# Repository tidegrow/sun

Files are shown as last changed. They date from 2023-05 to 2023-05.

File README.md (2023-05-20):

# Tidegrow Sun

Tidegrow Sun is an experimental low-power grow light.

## Pinout

Sun uses a non-standard MicroUSB pinout that is compatible with [Tidegrow Curator](https://github.com/tidegrow/curator):

| Signal | Description |
| --- | --- |
| VBUS | Power (5V) |
| D+ | LED PWM control input (3.3V) |
| D- | Photoresistor output (0-3.3V) |
| GND | Ground |

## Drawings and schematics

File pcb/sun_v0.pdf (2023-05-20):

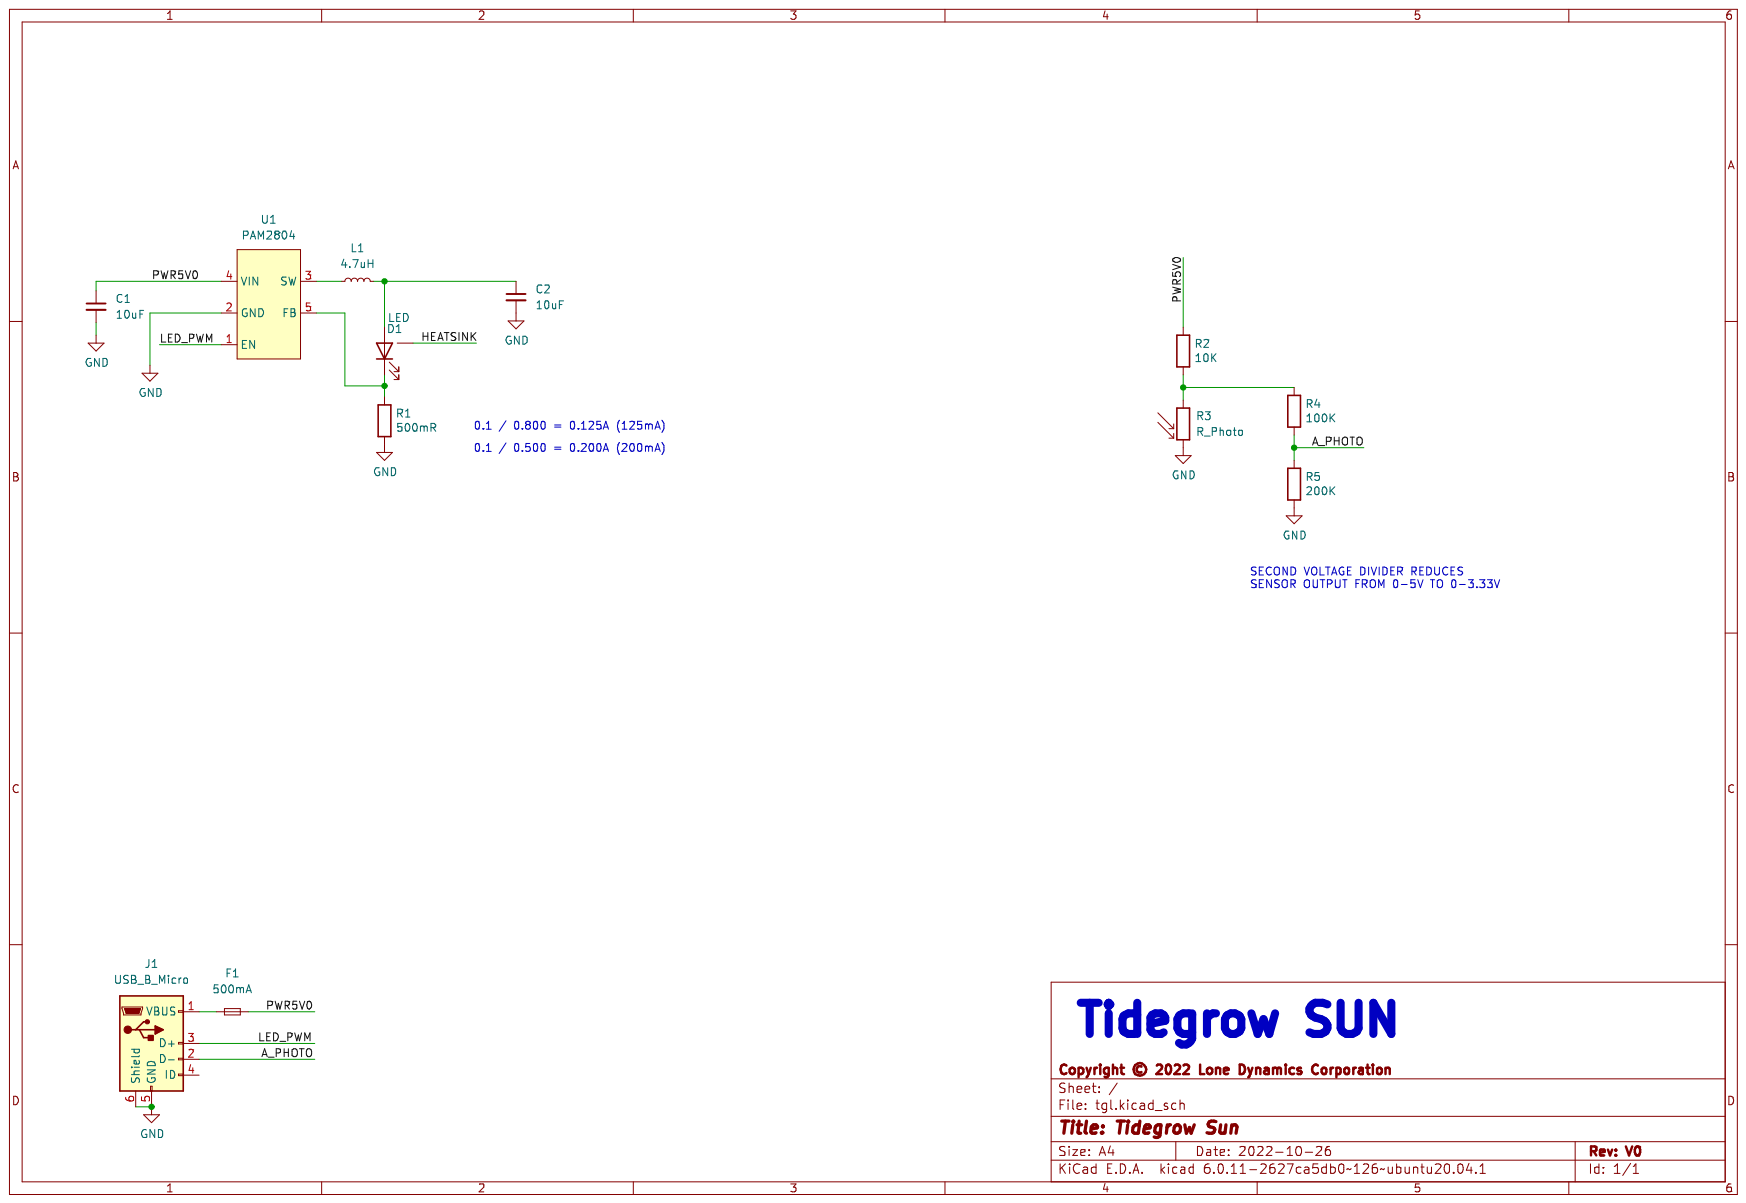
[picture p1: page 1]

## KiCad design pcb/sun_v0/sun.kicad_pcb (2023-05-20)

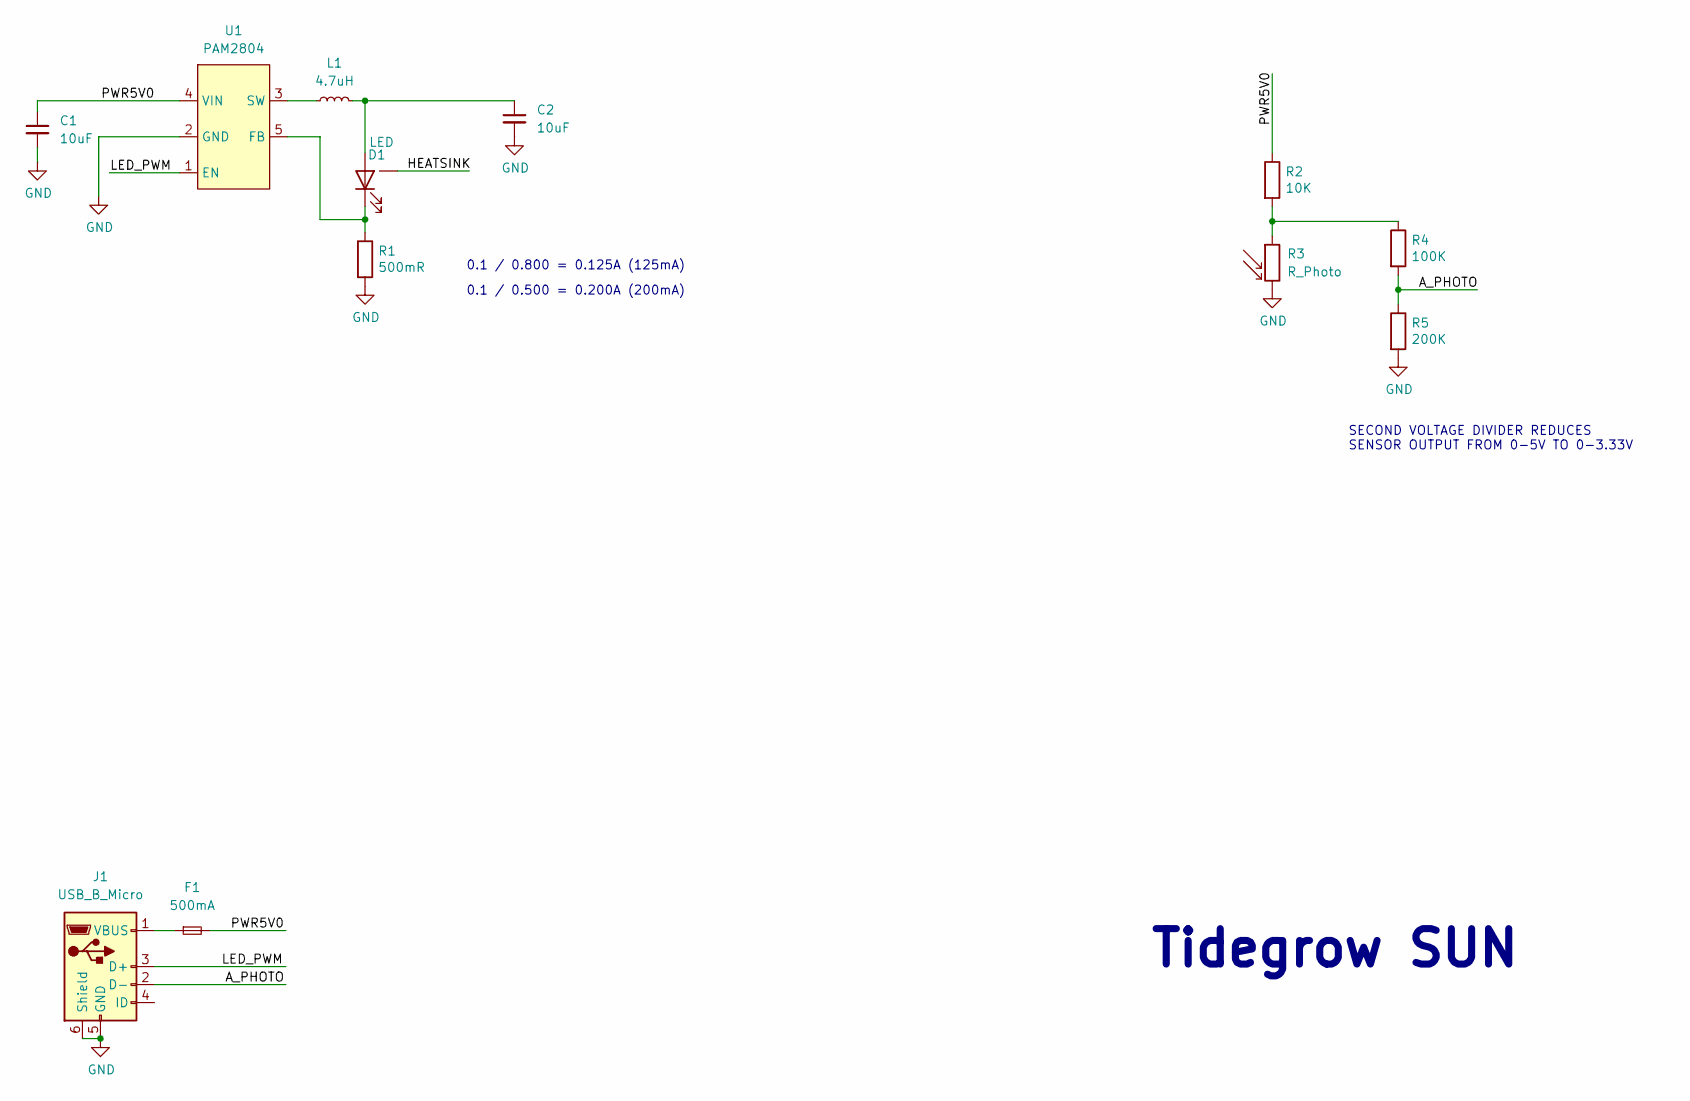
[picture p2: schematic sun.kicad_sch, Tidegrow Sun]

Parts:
C1, C2: 10uF; C_0603_1608Metric
D1: LED; LED_1W_3W_R8
F1: 500mA; Fuse_0805_2012Metric
J1: USB_B_Micro; Generic_Chinese_USB_MicroB_Horizontal_Socket_Circular_Holes
L1: 4.7uH; L_1008_2520Metric
R1: 500mR; R_2010_5025Metric
R2: 10K; R_0603_1608Metric
R3: R_Photo; R_PHOTO_3624
R4: 100K; R_0603_1608Metric
R5: 200K; R_0603_1608Metric
U1: PAM2804; SOT-23-5

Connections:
/A_PHOTO: J1.2 (D-), R4.2, R5.1
/HEATSINK: D1.3 (HEATSINK)
/LED_PWM: J1.3 (D+), U1.1 (EN)
/PWR5V0: C1.1, F1.2, R2.1, U1.4 (VIN)
GND: C1.2, C2.2, J1.5 (GND), J1.6 (Shield), R1.2, R3.2, R5.2, U1.2 (GND)
unnamed: C2.1, D1.2 (A), L1.2
unnamed: D1.1 (K), R1.1, U1.5 (FB)
unnamed: F1.1, J1.1 (VBUS)
unnamed: L1.1, U1.3 (SW)
unnamed: R2.2, R3.1, R4.1

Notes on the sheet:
SECOND VOLTAGE DIVIDER REDUCES SENSOR OUTPUT FROM 0-5V TO 0-3.33V
0.1 / 0.800 = 0.125A (125mA)
Tidegrow SUN
0.1 / 0.500 = 0.200A (200mA)

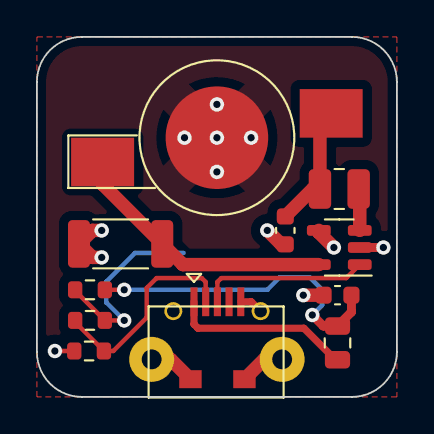
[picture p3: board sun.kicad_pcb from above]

Board: 2 copper layers, 20.0 x 20.0 mm, 12 parts (1 on the bottom side), 9 nets.

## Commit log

2023-05-20 add pcb
    [tgl.kicad_pcb, tgl.kicad_sch]
2023-05-20 rename pcb
    [sun.kicad_pcb, sun.kicad_sch]

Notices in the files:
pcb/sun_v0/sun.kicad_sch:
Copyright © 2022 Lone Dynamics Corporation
